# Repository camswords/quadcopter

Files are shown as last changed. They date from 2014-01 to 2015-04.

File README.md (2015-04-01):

The ThoughtWorks Sydney Quadcopter
==========

The ThoughtWorks Sydney Quadcopter is a quadcopter that is being built by the ThoughtWorks Sydney Community. 

To find out parts we have used, lessons we have learnt check out http://www.camswords.com/blog. To see photos of the quadcopter as it is built check out http://www.pinterest.com/camswords/the-thoughtworks-sydney-maker-day.

#### To disable Read Out Protection on new devices

1. Download the ST Link utility tool http://www.st.com/web/en/catalog/tools/PF258168

2. Install it on windows

3. Connect your ST Link USB device to your computer, and to your mini-m4

4. Try to connect, it will barf about not having permission. Set the Read Out Protection (under Option Bytes) to Level 0, no protection. 

5. Note that setting it to 2 will brick your mini-m4.

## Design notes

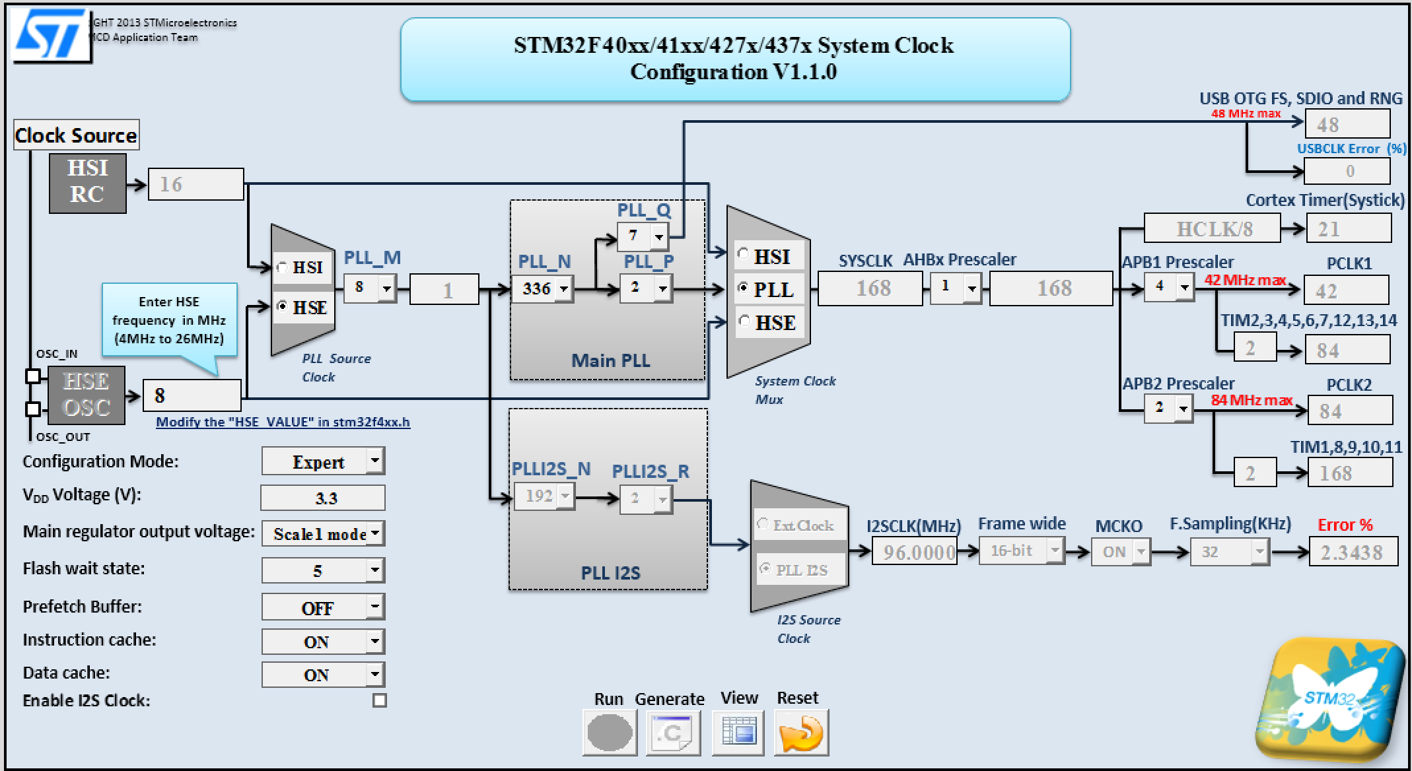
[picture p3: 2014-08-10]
src/stm32f4/reference/clock-speed.png

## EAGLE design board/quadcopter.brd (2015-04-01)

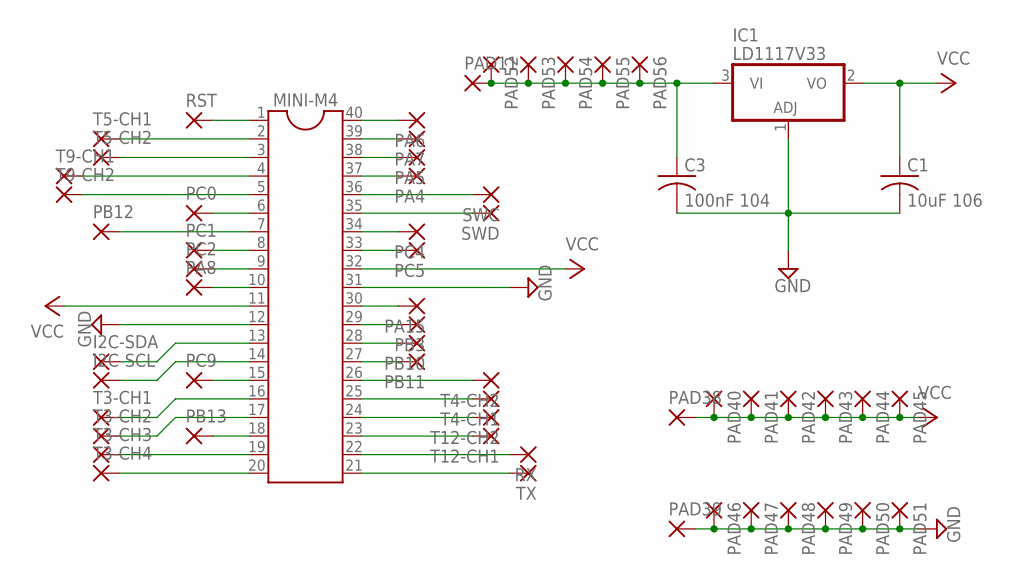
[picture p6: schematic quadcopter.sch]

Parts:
C1: 10uF 106; C025-040X050
C3: 100nF 104; C025-040X050
I2C-SCL, I2C-SDA: 1,6/0,8
IC1: LD1117V33; TO220H
MINI-M4: DIL40
PA4, PA5, PA6, PA7, PA8, PA15: 1,6/0,8
PAD11, PAD38, PAD39, PAD40, PAD41, PAD42, PAD43, PAD44, PAD45, PAD46, PAD47, PAD48, PAD49, PAD50, PAD51, PAD52, PAD53, PAD54, PAD55, PAD56: 1,6/0,8
PB3, PB10, PB11, PB12, PB13: 1,6/0,8
PC0, PC1, PC2, PC4, PC5, PC9: 1,6/0,8
RST: 1,6/0,8
RX: 1,6/0,8
SWC: 1,6/0,8
SWD: 1,6/0,8
T3-CH1, T3-CH2, T3-CH3, T3-CH4, T4-CH1, T4-CH2, T5-CH1, T5-CH2, T9-CH1, T9-CH2, T12-CH1, T12-CH2: 1,6/0,8
TX: 1,6/0,8

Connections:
GND: C1.2, C3.2, IC1.1 (ADJ), MINI-M4.12, MINI-M4.31, PAD39.1, PAD46.1, PAD47.1, PAD48.1, PAD49.1, PAD50.1, PAD51.1
unnamed: MINI-M4.2, T5-CH1.1
unnamed: MINI-M4.1, RST.1
unnamed: MINI-M4.3, T5-CH2.1
unnamed: MINI-M4.4, T9-CH1.1
unnamed: MINI-M4.6, PC0.1
unnamed: MINI-M4.5, T9-CH2.1
unnamed: MINI-M4.7, PB12.1
unnamed: MINI-M4.8, PC1.1
unnamed: MINI-M4.9, PC2.1
unnamed: MINI-M4.10, PA8.1
unnamed: MINI-M4.16, T3-CH1.1
unnamed: MINI-M4.17, T3-CH2.1
unnamed: I2C-SDA.1, MINI-M4.13
unnamed: I2C-SCL.1, MINI-M4.14
unnamed: C3.1, IC1.3 (VI), PAD11.1, PAD52.1, PAD53.1, PAD54.1, PAD55.1, PAD56.1
unnamed: MINI-M4.15, PC9.1
unnamed: MINI-M4.40, PA6.1
unnamed: MINI-M4.18, PB13.1
unnamed: MINI-M4.19, T3-CH3.1
unnamed: MINI-M4.20, T3-CH4.1
unnamed: MINI-M4.39, PA7.1
unnamed: MINI-M4.37, PA4.1
unnamed: MINI-M4.38, PA5.1
unnamed: MINI-M4.36, SWC.1
unnamed: MINI-M4.35, SWD.1
unnamed: MINI-M4.33, PC5.1
unnamed: MINI-M4.34, PC4.1
unnamed: MINI-M4.30, PA15.1
unnamed: MINI-M4.29, PB3.1
unnamed: MINI-M4.28, PB10.1
unnamed: MINI-M4.26, T4-CH2.1
unnamed: MINI-M4.27, PB11.1
unnamed: MINI-M4.25, T4-CH1.1
unnamed: MINI-M4.24, T12-CH2.1
unnamed: MINI-M4.22, RX.1
unnamed: MINI-M4.23, T12-CH1.1
unnamed: MINI-M4.21, TX.1
VCC: C1.1, IC1.2 (VO), MINI-M4.11, MINI-M4.32, PAD38.1, PAD40.1, PAD41.1, PAD42.1, PAD43.1, PAD44.1, PAD45.1

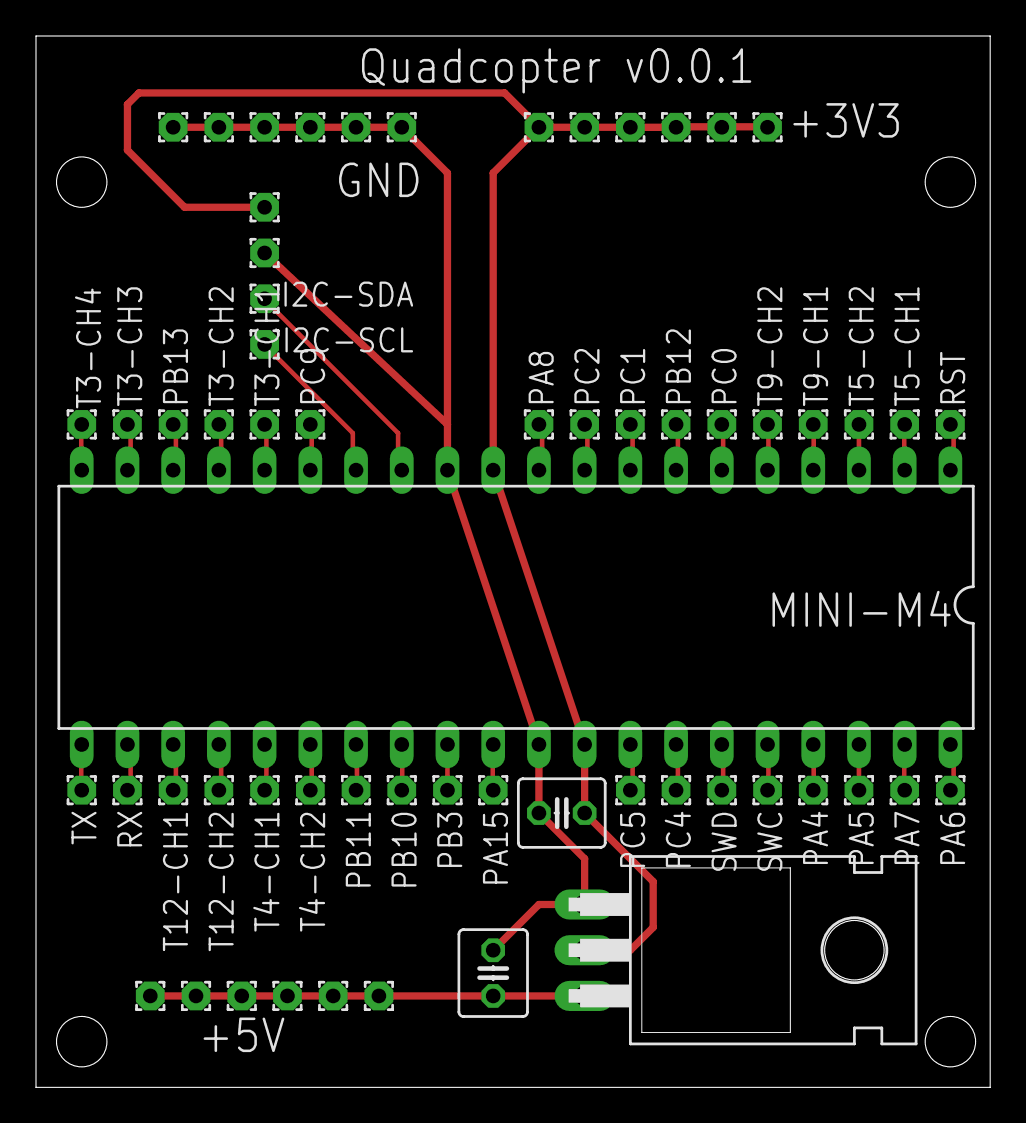
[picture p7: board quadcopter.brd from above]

Board: 2 copper layers, 53.0 x 58.4 mm, 60 parts (0 on the bottom side), 39 nets.

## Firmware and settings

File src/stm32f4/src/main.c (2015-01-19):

#include <stdint.h>

#include "../Libraries/STM32F4xx_StdPeriph_Driver/inc/stm32f4xx_gpio.h"
#include "accelerometer.h"
#include "analytics.h"
#include "angular_position.h"
#include "configuration.h"
#include "delay.h"
#include "gyroscope.h"
#include "i2c.h"
#include "on_board_leds.h"
#include "panic.h"
#include "pid.h"
#include "pwm.h"
#include "remote_controls.h"
#include "stm32f4xx.h"
#include "systick.h"
#include <stdlib.h>
#include <stdbool.h>

/* Performance fun tips:
 * Use the native register size wherever possible (32bit!). That way the processor doesn't have to do fancy scaling to get your register to the size it can handle
 * compile using hard float support
 */

/* Before attempting to fly:
 * understand the maximum and minimum airleron / elevator / rudder / throttle values
 * build a start motors sequence
 */

/* Things to do:
 *   - add a high pass filter to the gyroscope
 *   - add a low pass filter to the accelerometer
 *   - combine their outputs using a complimentary filter
 */

int main(void) {
	EnableTiming();
	InitialiseLeds();
	InitialisePanicButton();

	TurnOn(ORANGE_LED);

	InitialiseSysTick();

	InitialiseAnalytics(); // PC.10 (TX) and PC.11 (RX)
	InitialisePWM();
	ResetI2C();
	InitialiseI2C();	// PB.08 (SCL), PB.09 (SDA)
	Pid xAxisPid = InitialisePid(3, 0, 0);
	Pid yAxisPid = InitialisePid(3, 0, 0);


	/*
	* Throttle: PB.06 (TIM4),  Channel 1 (PB.07 indirectly used)
	* Rudder:   PA.00 (TIM5),  Channel 4 (PA.01 indirectly used)
	* Airleron: PE.05 (TIM9),  Channel 2 (PE.06 indirectly used)
	* Elevator: PB.14 (TIM12), Channel 3 (PB.15 indirectly used)
	*/
	InitialiseRemoteControls();

	// Uses Timer #3
	DutyCycle bProp = InitialisePWMChannel(GPIOB, GPIO_Pin_1, GPIO_PinSource1, 4); 	// (y axis)
	DutyCycle eProp = InitialisePWMChannel(GPIOA, GPIO_Pin_7, GPIO_PinSource7, 2);	// (y axis)
	DutyCycle cProp = InitialisePWMChannel(GPIOB, GPIO_Pin_0, GPIO_PinSource0, 3);	// (x axis)
	DutyCycle aProp = InitialisePWMChannel(GPIOA, GPIO_Pin_6, GPIO_PinSource6, 1);	// (x axis)

	InitialiseAngularPosition();

	TurnOff(ORANGE_LED);
	TurnOn(YELLOW_LED);

	/* turn the motors off, until we get the go ahead from the user */
	uint8_t armingSequenceStep = ARMING_SEQUENCE_LOW_THROTTLE_REQUIRED;
	uint32_t armingSequenceTimeLastStepExecuted = 0;

	bProp.set(1000);
	eProp.set(1000);
	cProp.set(1000);
	aProp.set(1000);

	while (armingSequenceStep != ARMING_SEQUENCE_ARMED || ARMING_SEQUENCE_IS_DISABLED) {
		float thrust = ReadRemoteThrottle();

		if (secondsElapsed > armingSequenceTimeLastStepExecuted) {

			if (armingSequenceStep == ARMING_SEQUENCE_LOW_THROTTLE_REQUIRED && thrust == 0.0) {
				armingSequenceStep = ARMING_SEQUENCE_HIGH_THROTTLE_REQUIRED;
				armingSequenceTimeLastStepExecuted = secondsElapsed;

			} else if (armingSequenceStep == ARMING_SEQUENCE_HIGH_THROTTLE_REQUIRED && thrust == 100.0) {
				armingSequenceStep = ARMING_SEQUENCE_LOW_THROTTLE_REQUIRED_AGAIN;
				armingSequenceTimeLastStepExecuted = secondsElapsed;

			} else if (armingSequenceStep == ARMING_SEQUENCE_LOW_THROTTLE_REQUIRED_AGAIN && thrust == 0.0) {
				armingSequenceStep = ARMING_SEQUENCE_ARMED;
				armingSequenceTimeLastStepExecuted = secondsElapsed;

				TurnOff(YELLOW_LED);
				TurnOn(BLUE_LED);
			}
		}

		WaitAFewMillis(10);
	}


	/* go go go! */

	uint16_t loopsPerSecond = 0;
	uint32_t thisSecond = 0;

	while(1) {
		loopsPerSecond++;
		ReadAngularPosition();

		float thrust = ReadRemoteThrottle();
		float baseMotorSpeed = 0;
		float motorAdjustment = 0;
		float bMotorSpeed = 0.0;
		float eMotorSpeed = 0.0;
		float cMotorSpeed = 0.0;
		float aMotorSpeed = 0.0;
		float xAdjustment = 0.0;
		float yAdjustment = 0.0;

		if ((armingSequenceStep != ARMING_SEQUENCE_ARMED || ARMING_SEQUENCE_IS_DISABLED) && secondsElapsed > armingSequenceTimeLastStepExecuted) {
			if (armingSequenceStep == ARMING_SEQUENCE_LOW_THROTTLE_REQUIRED && thrust == 0.0) {
				armingSequenceStep = ARMING_SEQUENCE_HIGH_THROTTLE_REQUIRED;
				armingSequenceTimeLastStepExecuted = secondsElapsed;

			} else if (armingSequenceStep == ARMING_SEQUENCE_HIGH_THROTTLE_REQUIRED && thrust == 100.0) {
				armingSequenceStep = ARMING_SEQUENCE_LOW_THROTTLE_REQUIRED_AGAIN;
				armingSequenceTimeLastStepExecuted = secondsElapsed;

			} else if (armingSequenceStep == ARMING_SEQUENCE_LOW_THROTTLE_REQUIRED_AGAIN && thrust == 0.0) {
				armingSequenceStep = ARMING_SEQUENCE_ARMED;
				armingSequenceTimeLastStepExecuted = secondsElapsed;

				TurnOff(YELLOW_LED);
				TurnOn(BLUE_LED);
			}
		} else if (armingSequenceStep == ARMING_SEQUENCE_ARMED) {
			xAdjustment = CalculatePidAdjustment(&xAxisPid, angularPosition.x, 0.0);
			yAdjustment = CalculatePidAdjustment(&yAxisPid, angularPosition.y, 0.0);

			if (xAdjustment < PID_MINIMUM_BOUND) { xAdjustment = PID_MINIMUM_BOUND; }
			if (xAdjustment > PID_MAXIMUM_BOUND) { xAdjustment = PID_MAXIMUM_BOUND; }
			if (yAdjustment < PID_MINIMUM_BOUND) { yAdjustment = PID_MINIMUM_BOUND; }
			if (yAdjustment > PID_MAXIMUM_BOUND) { yAdjustment = PID_MAXIMUM_BOUND; }

			if (thrust == 0.0) {
				/* always turn it off when the throttle is zero, independent of throttle constants */
				bProp.set(1000);
				eProp.set(1000);
				cProp.set(1000);
				aProp.set(1000);
			} else {
				/* throttle is converted to a range of -50 to +50 */
				baseMotorSpeed = MOTOR_SPEED_REQUIRED_FOR_LIFT + (THROTTLE_SENSITIVITY * (thrust - 50.0));

				bMotorSpeed = baseMotorSpeed + yAdjustment;
				eMotorSpeed = baseMotorSpeed - yAdjustment;
				cMotorSpeed = baseMotorSpeed + xAdjustment;
				aMotorSpeed = baseMotorSpeed - xAdjustment;

				/* adjust all motor speeds if one motor is outside motor speed bounds */
				/* this is a deliberate choice to prioritise desired angular position over desired thrust */
				float smallestMotorSpeed = MAXIMUM_MOTOR_SPEED;
				float largestMotorSpeed = MINIMUM_MOTOR_SPEED;

				if (bMotorSpeed < smallestMotorSpeed) { smallestMotorSpeed = bMotorSpeed; }
				if (bMotorSpeed > largestMotorSpeed) { largestMotorSpeed = bMotorSpeed; }
				if (eMotorSpeed < smallestMotorSpeed) { smallestMotorSpeed = eMotorSpeed; }
				if (eMotorSpeed > largestMotorSpeed) { largestMotorSpeed = eMotorSpeed; }
				if (cMotorSpeed < smallestMotorSpeed) { smallestMotorSpeed = cMotorSpeed; }
				if (cMotorSpeed > largestMotorSpeed) { largestMotorSpeed = cMotorSpeed; }
				if (aMotorSpeed < smallestMotorSpeed) { smallestMotorSpeed = aMotorSpeed; }
				if (aMotorSpeed > largestMotorSpeed) { largestMotorSpeed = aMotorSpeed; }

				if (smallestMotorSpeed < MINIMUM_MOTOR_SPEED) {
					motorAdjustment = MINIMUM_MOTOR_SPEED - smallestMotorSpeed;
				} else if (largestMotorSpeed > MAXIMUM_MOTOR_SPEED) {
					motorAdjustment = MAXIMUM_MOTOR_SPEED - largestMotorSpeed;
				}

				/* apply adjusted motor speeds to the motors */
				bMotorSpeed = bMotorSpeed + motorAdjustment;
				eMotorSpeed = eMotorSpeed + motorAdjustment;
				cMotorSpeed = cMotorSpeed + motorAdjustment;
				aMotorSpeed = aMotorSpeed + motorAdjustment;

				bProp.set(bMotorSpeed);
				eProp.set(eMotorSpeed);
				cProp.set(cMotorSpeed);
				aProp.set(aMotorSpeed);
			}
		}

		if (thisSecond != secondsElapsed) {
			uint8_t loopReference = rand() & 0xFF;

			RecordIntegerMetric(METRIC_SECONDS_ELAPSED, loopReference, secondsElapsed);
			RecordIntegerMetric(METRIC_LOOP_FREQUENCY, loopReference, loopsPerSecond);
			RecordFloatMetric(METRIC_GYROSCOPE_X_POSITION, loopReference, gyroscopeReading.x);
			RecordFloatMetric(METRIC_GYROSCOPE_Y_POSITION, loopReference, gyroscopeReading.y);
			RecordFloatMetric(METRIC_GYROSCOPE_Z_POSITION, loopReference, gyroscopeReading.z);
			RecordFloatMetric(METRIC_GYROSCOPE_TEMPERATURE, loopReference, gyroscopeReading.gyroscopeTemperature);
			RecordIntegerMetric(METRIC_GYROSCOPE_SAMPLE_RATE, loopReference, gyroscopeReading.readings);
			RecordFloatMetric(METRIC_PROPELLOR_B_SPEED, loopReference, bMotorSpeed);
			RecordFloatMetric(METRIC_PROPELLOR_E_SPEED, loopReference, eMotorSpeed);
			RecordFloatMetric(METRIC_PROPELLOR_C_SPEED, loopReference, cMotorSpeed);
			RecordFloatMetric(METRIC_PROPELLOR_A_SPEED, loopReference, aMotorSpeed);
			RecordFloatMetric(METRIC_PID_X_ADJUSTMENT, loopReference, xAdjustment);
			RecordFloatMetric(METRIC_PID_Y_ADJUSTMENT, loopReference, yAdjustment);
			RecordFloatMetric(METRIC_REMOTE_PID_PROPORTIONAL, loopReference, xAxisPid.proportional);
			RecordFloatMetric(METRIC_REMOTE_THROTTLE, loopReference, thrust);
			RecordFloatMetric(METRIC_ACCELEROMETER_X_POSITION, loopReference, accelerometerReading.x);
			RecordFloatMetric(METRIC_ACCELEROMETER_Y_POSITION, loopReference, accelerometerReading.y);
			RecordFloatMetric(METRIC_ACCELEROMETER_Z_POSITION, loopReference, accelerometerReading.z);
			RecordIntegerMetric(METRIC_ACCELEROMETER_SAMPLE_RATE, loopReference, accelerometerReading.readings);
			RecordFloatMetric(METRIC_ANGULAR_X_POSITION, loopReference, angularPosition.x);
			RecordFloatMetric(METRIC_ANGULAR_Y_POSITION, loopReference, angularPosition.y);
			RecordFloatMetric(METRIC_ANGULAR_Z_POSITION, loopReference, angularPosition.z);
			RecordIntegerMetric(METRIC_METRICS_BUFFER_SIZE, loopReference, metricsRingBuffer.count);
			RecordFloatMetric(METRIC_DEBUG_VALUE_1, loopReference, baseMotorSpeed);
			RecordFloatMetric(METRIC_DEBUG_VALUE_2, loopReference, motorAdjustment);

			loopsPerSecond = 0;
			accelerometerReading.readings = 0;
			gyroscopeReading.readings = 0;
			thisSecond = secondsElapsed;
			ClearWarnings();
		}

		if (intermediateMillis % ANALYTICS_FLUSH_FREQUENCY == 0) {
			FlushMetrics();
		}
	}
}

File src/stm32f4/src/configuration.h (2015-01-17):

#ifndef CONFIGURATION_H_
#define CONFIGURATION_H_

// ARMING_SEQUENCE
#define ARMING_SEQUENCE_LOW_THROTTLE_REQUIRED		0
#define ARMING_SEQUENCE_HIGH_THROTTLE_REQUIRED		1
#define ARMING_SEQUENCE_LOW_THROTTLE_REQUIRED_AGAIN 2
#define ARMING_SEQUENCE_ARMED						3

#define ARMING_SEQUENCE_IS_DISABLED					0

// THROTTLE CALIBRATION
/* use different values of motor speed if the quad ascends / descends too quickly with a centered throttle */
#define MOTOR_SPEED_REQUIRED_FOR_LIFT				1100.0

/* use different values of sensitivity if the quad ascends / descends too quickly when changing the throttle.
 * this is used in a calculation MOTOR_SPEED + (SENS. * THROTTLE) where THROTTLE is in the range -50 : +50.
 */
#define THROTTLE_SENSITIVITY						10.0

// PID
/* any pid calculations outside these bounds will be reduced to the bound value */
#define PID_MINIMUM_BOUND							-100.0
#define PID_MAXIMUM_BOUND							100.0


// MOTOR SPEED
#define MINIMUM_MOTOR_SPEED							1000
#define MAXIMUM_MOTOR_SPEED							2000


// ANGULAR POSITION
#define HOW_MUCH_I_TRUST_THE_GYROSCOPE     			0.98f
#define HOW_MUCH_I_TRUST_THE_ACCELEROMETER			1 - HOW_MUCH_I_TRUST_THE_GYROSCOPE
#define GYROSCOPE_SAMPLE_RATE              			1.0f / (1000.0f / 1.0f)	/* sample rate is closer to 1.74k per second now that time is not measured */


// ANALYTICS
#define ANALYTICS_FLUSH_FREQUENCY 		   			1000 / 200 	/* how often to flush the metrics (20 times per second) */
#define	ANALYTICS_CHARACTERS_TO_SEND_PER_FLUSH 		5

// METRICS
#define METRIC_SECONDS_ELAPSED								0
#define METRIC_LOOP_FREQUENCY								1
#define METRIC_GYROSCOPE_X_POSITION							2
#define METRIC_GYROSCOPE_Y_POSITION							3
#define METRIC_GYROSCOPE_Z_POSITION							4
#define METRIC_GYROSCOPE_TEMPERATURE						5
#define METRIC_GYROSCOPE_SAMPLE_RATE						6
#define METRIC_ACCELEROMETER_X_POSITION						7
#define METRIC_ACCELEROMETER_Y_POSITION						8
#define METRIC_ACCELEROMETER_Z_POSITION						9
#define METRIC_ACCELEROMETER_SAMPLE_RATE					10
#define METRIC_ANGULAR_X_POSITION							11
#define METRIC_ANGULAR_Y_POSITION							12
#define METRIC_ANGULAR_Z_POSITION							13
#define METRIC_PID_X_ADJUSTMENT								14
#define METRIC_PID_Y_ADJUSTMENT								15
#define METRIC_REMOTE_PID_PROPORTIONAL						16
#define METRIC_REMOTE_PID_INTEGRAL							27
#define METRIC_REMOTE_THROTTLE								17
#define METRIC_PROPELLOR_B_SPEED							18
#define METRIC_PROPELLOR_E_SPEED							19
#define METRIC_PROPELLOR_C_SPEED							20
#define METRIC_PROPELLOR_A_SPEED							21
#define METRIC_METRICS_BUFFER_SIZE							22
#define METRIC_DEBUG_VALUE_1								23
#define METRIC_DEBUG_VALUE_2								24
#define METRIC_DEBUG_VALUE_3								25
#define METRIC_DEBUG_VALUE_4								26

#endif

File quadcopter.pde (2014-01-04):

/*
  Blink
  Turns on an LED on for one second, then off for one second, repeatedly.
 
  This example code is in the public domain.
 */
 
// Pin 13 has an LED connected on most Arduino boards.
// give it a name:
int led = 13;

// the setup routine runs once when you press reset:
void setup() {                
  // initialize the digital pin as an output.
  pinMode(led, OUTPUT);     
}

// the loop routine runs over and over again forever:
void loop() {
  digitalWrite(led, HIGH);   // turn the LED on (HIGH is the voltage level)
  delay(400);               // wait for a second
  digitalWrite(led, LOW);    // turn the LED off by making the voltage LOW
  delay(200);               // wait for a second
}

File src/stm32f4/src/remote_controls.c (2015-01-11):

#include <remote_controls.h>

void InitialiseRemoteControls() {
  /* throttle: all together now! power (collective pitch?)
   * Channel 1 on the RC receiver
   */
  throttle = MeasurePWMInput(TIM4, GPIOB, GPIO_Pin_6, GPIO_PinSource6); 	// channel 2 - PB.07

  /* rudder: spin to the left or right on a flat plane
   * Channel 4 on the RC receiver
   */
  remotePidProportional = MeasurePWMInput(TIM5, GPIOA, GPIO_Pin_0, GPIO_PinSource0); 		// channel 2 - PA.01

  /* airleron: fly sideways left or right
   * Channel 2 on the RC receiver
   */
  remotePidIntegral = MeasurePWMInput(TIM9, GPIOE, GPIO_Pin_5, GPIO_PinSource5);	// channel 2 - PE.05

  /* elevator: fly forwards or backwards
   * Channel 3 on the RC receiver
   */
  resetAngularPosition = MeasurePWMInput(TIM12, GPIOB, GPIO_Pin_14, GPIO_PinSource14); // channel 2 - PB.15
}

/* note this makes assumptions about the minimum and maximum of duty cycles */
float CalculatePercentageOfMaximum(float dutyCycle, float frequency) {
	/* how can I tell if something is NAN? */

	/* A duty cycle of 2ms is on for 11% of the time @ 55Hz (18.181818ms period) */
	float maximum = 2.0 / (1000 / frequency) * 100;
	/* A duty cycle of 1ms is on for 5.5% of the time @ 55Hz (18.181818ms period) */
	float minimum = 1.0 / (1000 / frequency) * 100;

	float percentageOn = (dutyCycle - (maximum - minimum)) / minimum * 100.0;

	if (percentageOn > 100.0) {
		return 100.0;
	}

	if (percentageOn < 0.0) {
		return 0.0;
	}

	return percentageOn;
}

float ReadRemoteThrottle() {
	return CalculatePercentageOfMaximum(throttle->dutyCycle, throttle->frequency);
}

float ReadRemotePidProportional() {
	return CalculatePercentageOfMaximum(remotePidProportional->dutyCycle, remotePidProportional->frequency);
}

float ReadRemotePidIntegral() {
	return CalculatePercentageOfMaximum(remotePidIntegral->dutyCycle, remotePidIntegral->frequency);
}

float ReadResetAngularPosition() {
	return CalculatePercentageOfMaximum(resetAngularPosition->dutyCycle, resetAngularPosition->frequency);
}

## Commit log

2014-01-04 Updated license to have my full name, added the example makefile for command line arduino uploading found at http://forum.arduino.cc/index.php/topic,37734.0.html
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2014-01-04 Moved the quadcopter to be a CPP file so that we can write C++ code properly. Upgraded Arduino, the readme reflects this in the tested version. Building the code will create a temporary build directo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
2014-01-04 Added a scons build file because it has much better integration with the arduino source code.
2014-01-04 the artifact is created in the build directory so that we don’t pollute the root directory.
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2014-01-04 The servo code (not just the header) is compiled into the hex file.
2014-01-07 The compile script defines which Arduino libraries to compile along with the Quadcopter source code.
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2014-01-08 Added an event loop. This should make it easy to add and combine sensors and actuators.
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2014-02-04 Wrap the servo in a motor class to make it more readable.
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2014-02-24 added a base structure for working out the pitch, yaw and roll of the quaddy.
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2014-03-16 ensure the brackets are included when are asserting the code was sent
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2014-03-17 move all of the on error handlers to the promise chain
2014-03-20 print out the log when errors occur
2014-03-26 cam/sam: removed minification until we need it, removed mini test until it can print errors, wrote our first test!
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2014-04-20 renamed adjust throttles to be kebab case; added tests to ensure that all propellers are accelerated to the throttle
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2014-04-20 fail to create a propeller when no pin is specified
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2014-04-20 converted the boundaries of the propeller throttle to be between 1000 and 2000
2014-04-21 rename the failWhale to kebab case like the rest of the code
2014-04-21 rename the setWatch module to be kebab case like the rest of the code
2014-04-21 converted the pid to be an amd module that can be deployed to the quad
2014-04-21 removed old pid stuff, remove jasmine node as it is no longer used
2014-04-23 ensure the propeller does not adjust throttle when the value is not a number
2014-04-27 created an observer that will save the frequency that the quad loops over sensing and adjusting throttles
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2014-05-03 print the memory usage for the AMD loader as well as the source files
2014-05-04 print a better error message when no espruino is connected and strategy is find first
2014-05-12 clear the callbacks once a promise has been resolved, this reduces the memory footprint
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2014-05-15 moved the memory sample coffee files into the parent namespace, there isnt enough files to warrant separate directories
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2014-06-09 use analogWrite to write the throttle to the escs, it is more reliable than digital pulse.
2014-06-09 ensure the throttle is a number before saving it into the repository
2014-06-09 watch both rising and falling edges so that we can calculate the length of the pwm pulse width
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2014-06-09 the analytics repository understands how to get the throttle and the loop count
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2014-06-09 record the output throttle, this hopefully should help determine why the motors intermittently turn off
2014-06-09 read the pwm signal in exactly as we want to send it out, this should mean the espruino has less to do.
2014-06-09 remove the throttle mapping, as the pwm input is directly in the format of the output there is no need for this.
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2014-06-23 the deploy script deleted the old build directory to ensure recompile every time; added a lua file that can trigger an interrupt.
2014-08-06 added the libraries and an initial make file that will build the bin file to be deployed to a stm32 microcontroller
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2014-08-07 reverted the cpu hogging delay
    [main.c]
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2014-08-17 add an openocd script that can deploy the latest quadcopter to the device
    [deploy.cfg]
2014-08-17 refactored the shell deploy script into the makefile, added cute little echos to make it easier to understand what is happening during the deploy
    [deploy.cfg]
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2014-08-21 added a test harness to verify whether the pwm input is correct or not
    [main.c]
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2014-08-25 made the pwm input flexible to abstract the timer, this will facilitate more inputs being added shortly.
    [main.c, pwm_input.c]
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2014-08-26 added resets in an attempt to avoid the deploy timeout problem
    [deploy.cfg]
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2014-09-08 added the possible error situations for i2c if ever we get into having to deal with them
    [i2c.c]
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2014-09-15 attempting to use the gyroscope as a way of determining the angular position, so far it seems to be very unstable.
    [angular_position.c, gyroscope.c, main.c]
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2014-09-15 removed uncommented code, send the analytics earlier to ensure loops per second isnt being reset
    [main.c]
2014-09-26 skip the hardfault when the sensor read of the gyro is not comprehensible.
    [angular_position.c, gyroscope.c]
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2014-09-27 added the ability to factor gyro drift into the angular position reading
    [angular_position.c, gyroscope.c, main.c]
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2014-09-27 calibrate the gyro drift to ensure more accurate readings
    [angular_position.c, gyroscope.c]
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2014-09-28 reset the angular position to zero every ten seconds to make it easier to debug
    [angular_position.c, main.c]
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2014-10-01 remove the reset every 60 seconds, ensure that the pid is used to set not update. this means that the pid will behave more functional
    [main.c]
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2014-10-08 add the ability to manually reset the angular position to zero
    [main.c, remote_controls.c]
2014-10-08 remove the magnetometer code, it looks like it is sending to the wrong address
    [magnetometer.c]
2014-10-08 Revert "ensure we only use the angular position when we can trust its value"
    This reverts commit ccca8ee1c8178dc9e3262ffe0e5f6883bd736434.
    [angular_position.c, gyroscope.c, i2c.c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]
2014-10-08 gradually adding back in the gyro error handling code until I find the problem
    [angular_position.c, i2c.c, main.c]
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2014-10-11 send the reset statistics out via the analytics
    [main.c]
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2014-10-11 smooth the remote controls so that the angular position is not reset unless we press the button on the handset
    [main.c, remote_controls.c]
2014-10-12 upped the threshold on the smoothing to remove noise
    [remote_controls.c]
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2014-10-12 use the gyro at the lowest bandwidth low pass filter, it should amount to less noise
    [gyroscope.c]
2014-10-12 reduce pwm input noise whose value is far too low
    [pwm_input.c]
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2014-10-14 remove the drift offset, this should be instead done using a low pass filter.
    [angular_position.c, gyroscope.c]
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2014-11-02 fixed the broken angular position dashboard widget, ensure angular position is accelerometer only; turn the props off after they have been initialised
    [angular_position.c, main.c]
2014-11-02 reversed the x axis props as they were backwards
    [main.c]
2014-11-30 use the throttle from the remote control now that it has been fixed
    [main.c]
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2014-12-13 clock i2c peripherals so that they dont turn on blocking the i2c bus when there was a previous error
    [i2c.c, main.c]
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2014-12-14 enable clock stretching to give peripherals a chance to catchup if things are moving too fast
    [i2c.c]
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2014-12-15 make a distinction between warnings and errors; treat i2c bus errors as warnings; it seems the gyro forgets to send the eight byte every now and again
    [angular_position.c, i2c.c, main.c]
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2014-12-15 reset the i2c bus when errors occur
    [angular_position.c, i2c.c, main.c]
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2014-12-17 separate configuration into defines in one file
    [configuration.h]
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2014-12-28 replace the analytics with mavlink
    [configuration.h]
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2015-01-07 revert the mavlink changes. The mavlink clients didn't seem very useful and I found it hard to send all of the messages that I wanted.
    [configuration.h]
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2015-01-07 metrics are sent using the new format; this relys on more context at either end so that we can send a smaller message (and thus send more messages)
    [configuration.h]
2015-01-10 the analytics router understands the basics of the new metrics protocol
    [configuration.h]
2015-01-10 send true integer values as integers to remove slight error that was introduced
    [main.c]
2015-01-10 added more debug values to the analytics protocol; ensure we dont update the throttle when the IC1 and IC2 values are the same. I dont know why this happens, but I have post on STMs website so we'll 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
    [configuration.h]
2015-01-10 accidentally reverted the fix to 100% throttle, so putting it back
    [pwm_input.c]
2015-01-10 serial in function ensures that if a bit in the middle of the message is a start bit a new message is not started. This fixes the issue where 0% throttle was not displaying on the analytics dashboard
2015-01-10 cleaning up the pwm input signals means that I should no longer need input smoothing
    [remote_controls.c]
2015-01-11 add the ability to configure the x and y pid proportional values using the rc handset
    [configuration.h]
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2015-01-11 use the rc to manipulate pid proportional and integral, not the axis proportional
    [configuration.h]
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2015-01-17 changed the way that we interpret throttle so that the quad will hover by default
    [configuration.h]
2015-01-17 introduce bounds for the output of the pid calcuation
    [configuration.h]
2015-01-17 reduced the pid proportional and motor speed to take off to assist in tuning
    [configuration.h]
2015-01-17 converted tabs to spaces; added an arming sequence because I keep scaring the hell out of myself
    [configuration.h]
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2015-03-11 added the board schematics to source control
    [quadcopter.brd, quadcopter.sch]
2015-03-11 updated the board layout and routed the voltage regulator
    [quadcopter.brd, quadcopter.sch]
2015-03-14 the quadcopter board is shrunk to fit the frame
    [quadcopter.brd]
2015-03-17 updated quadcopter board to accomodate the 9dof
    [quadcopter.brd, quadcopter.sch]
2015-04-01 added the capacitor label to the board because I keep forgetting what it is
    [quadcopter.brd, quadcopter.sch]
